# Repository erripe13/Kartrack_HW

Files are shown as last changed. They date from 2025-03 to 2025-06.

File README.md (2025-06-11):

# Kartrak – Hardware

> **Dépôts associés** :  
> - [Kartrack_SW](https://github.com/erripe13/Kartrack_SW) – Code embarqué STM32 (FreeRTOS, GPS, LoRa, SD...)  
> - [Kartrack_HW](https://github.com/erripe13/Kartrack_HW) – **Ce dépôt** – Schéma et PCB du système  
> - [Kartrack_APP](https://github.com/erripe13/Kartrack_APP) – Application d’analyse et visualisation des données

## Présentation du projet Kartrak

Kartrak est un système embarqué de chronométrage et de télémétrie pour karting, conçu pour être fixé sur le volant. Il enregistre en temps réel les données de course (position GPS, accélérations, orientation) et les transmet en LoRa à l'appli desktop et les enregistre sur carte microSD. L’objectif est de proposer un outil complet pour les pilotes amateurs ou en compétition : analyse post-course, visualisation en temps réel par l'équipe, appel aux stands, comparaisons de trajectoires.

---

Le projet est basé sur la plateforme **STM32F746G-DISCO**, exploitant son STM32 puissant et ses périphériques avancés (écran TFT, SDMMC, i2c, SPI, UART) pour accélérer le développement hardware, éliminant l'étape d'implémentation écran/uC.

Ce dépôt contient les fichiers **KiCad** du schéma électronique et du circuit imprimé (PCB) conçu pour le système embarqué Kartrack. Il s’agit d’une carte d’interface et d’alimentation destinée à supporter la carte **STM32F746G-DISCO** tout en intégrant les composants spécifiques au projet.

Le système est alimenté à partir de **deux batteries 18650** montées en **parallèle**. Un **convertisseur boost (step-up)** élève la tension à 5 V pour alimenter la carte STM32F7 Discovery via ses broches VIN (arduino) et GND. Ces 5V sont réutilisés et abaissés à 3.3V avec un LDO. Un autre LDO permet la recharge des batteries.

Le PCB a été conçu dans une logique de prototypage rapide :
- **Réduction du temps de conception** en réutilisant une carte STM32 existante (la DISCO) plutôt qu’un microcontrôleur nu.
- Embarque les modules suivants :
  - LoRa : RA-01 (SPI). Le Lora nous permet de couvrir un grand espace de communication (Piste de Karting) sans passer par le réseau GSM et a aussi l'a avantage d'une faible consommation électrique.
  - GPS : Quectel L76 (UART). Le grand avantage de ce GPS est sa fréquence élevée d'acquisition, ici 5Hz. La norme des GPS est de 1Hz, mais pour un kart à 60km/h sur une piste de 1000m la norme n'est pas suffisante.
  - IMU : ICM-42605 (I²C). L'accéléromètre et le gyroscope nous permettent d'ajouter une donnée en plus à notre pilote. Ici le gyro est réglé sur la mesure la plus rapide, et l'accélaration la plus élevée (16G). En cas d'accident par exemple cette donnée peut être des plus intéressantes.  
     
---

## À venir

- Intégration directe d’un STM32 nu sur une version 1 de ce projet, considérant celle-ci comme une bêta ou un POC.
- Création d'un boîtier en conséquence plus fin et plus petit, potentiellement étanche.
- Amélioration de la partie RF pour une meilleure fiabilité du GPS et une plus grande portée du LoRa.

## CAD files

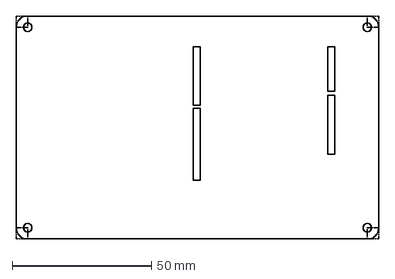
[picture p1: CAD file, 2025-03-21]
Mechanical/main_board_outline_and_arduino.dxf
130.0 x 80.0 mm

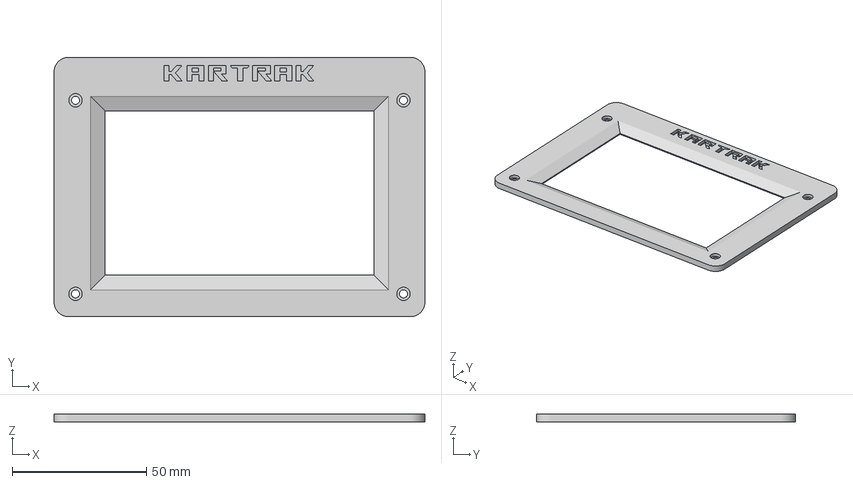
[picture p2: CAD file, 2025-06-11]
Mechanical/TOP_KARTRAK.3mf
138.0 x 96.5 x 3.00 mm

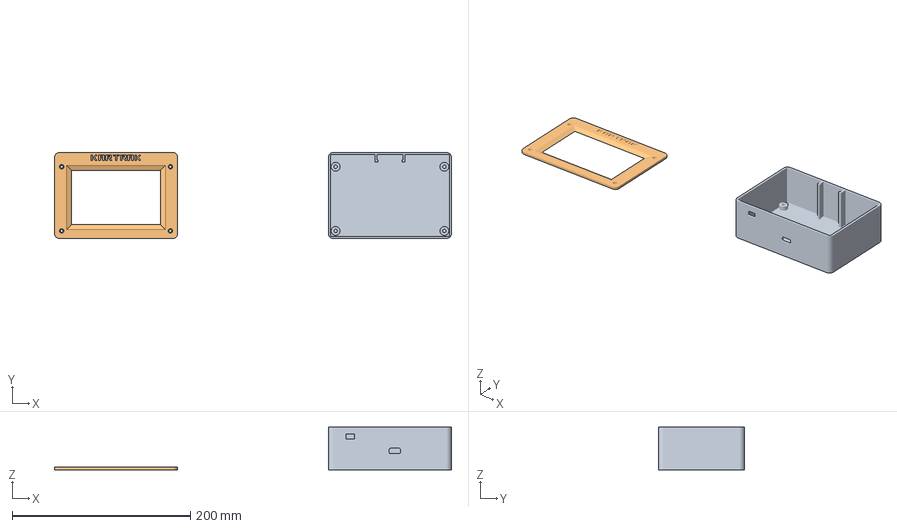
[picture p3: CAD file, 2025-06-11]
Mechanical/BOTTOM_KARTRAK.3mf
445.2 x 96.5 x 48.1 mm
BOTTOM_KARTRAK
TOP_KARTRAK

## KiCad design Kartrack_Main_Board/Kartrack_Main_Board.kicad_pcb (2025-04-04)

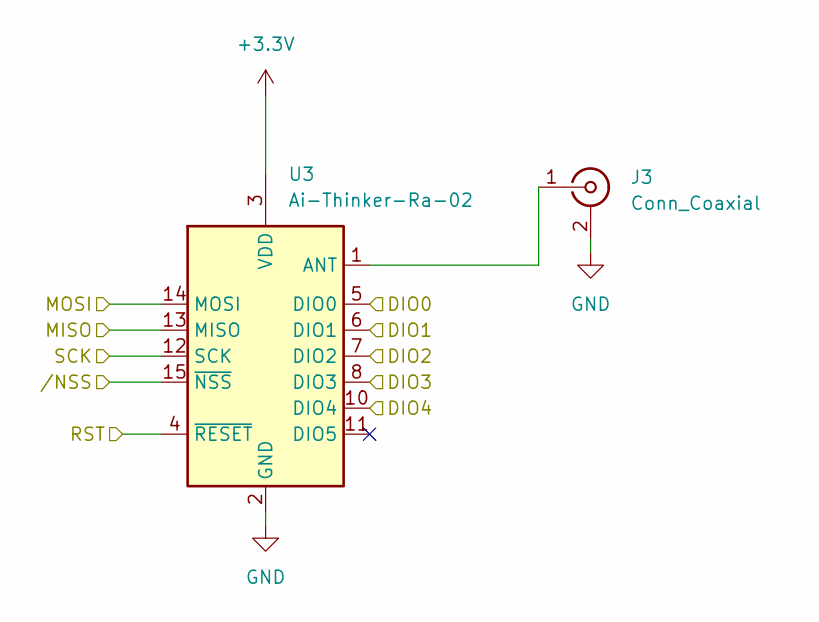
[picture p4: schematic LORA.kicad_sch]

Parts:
J3: Conn_Coaxial; U.FL_Molex_MCRF_73412-0110_Vertical
U3: Ai-Thinker-Ra-02; Ai-Thinker-Ra-01-LoRa

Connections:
+3.3V: U3.3 (VDD); also elsewhere on the board
/CONN/PA8: U3.8 (DIO3); also elsewhere on the board
/CONN/PA15: U3.7 (DIO2); also elsewhere on the board
/CONN/PB4: U3.10 (DIO4); also elsewhere on the board
/CONN/PB14_SPI2_MISO: U3.13 (MISO); also elsewhere on the board
/CONN/PB15_SPI2_MOSI: U3.14 (MOSI); also elsewhere on the board
/CONN/PF8_LORA_RST: U3.4 (~RESET); also elsewhere on the board
/CONN/PI1_SPI2_SCK: U3.12 (SCK); also elsewhere on the board
/CONN/PI2: U3.6 (DIO1); also elsewhere on the board
/CONN/PI3: U3.5 (DIO0); also elsewhere on the board
/CONN/PIO_SPI2_NSS: U3.15 (~NSS); also elsewhere on the board
GND: J3.2 (Ext), U3.2 (GND), U3.9 (GND), U3.16 (GND); also elsewhere on the board
unnamed: J3.1 (In), U3.1 (ANT)

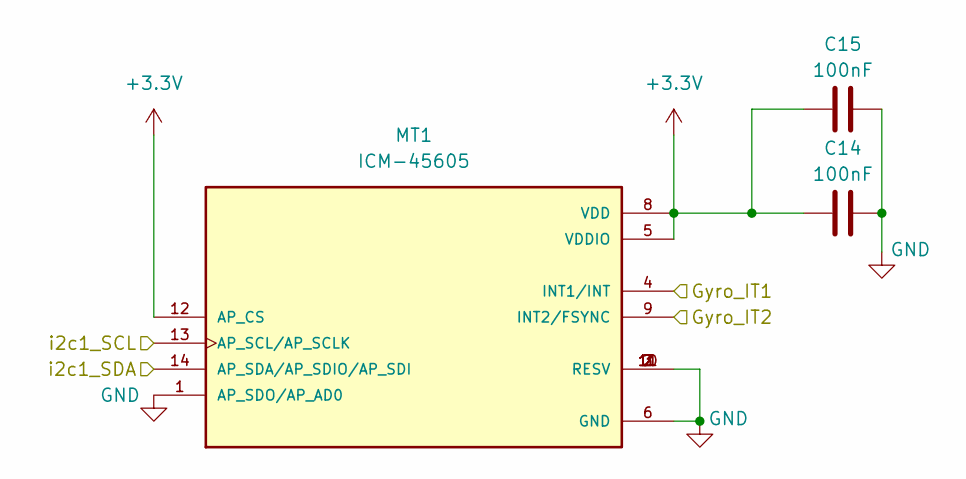
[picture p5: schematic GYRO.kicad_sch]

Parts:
C14, C15: 100nF; C_0402_1005Metric
MT1: ICM-45605; IC_ICM-45605; PARTREV 1.7

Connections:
+3.3V: C14.1, C15.1, MT1.5 (VDDIO), MT1.8 (VDD), MT1.12 (AP_CS); also elsewhere on the board
/CONN/PB8_SCL: MT1.13 (AP_SCL/AP_SCLK); also elsewhere on the board
/CONN/PB9_SDA: MT1.14 (AP_SDA/AP_SDIO/AP_SDI); also elsewhere on the board
/CONN/PF6: MT1.9 (INT2/FSYNC); also elsewhere on the board
/CONN/PG7: MT1.4 (INT1/INT); also elsewhere on the board
GND: C14.2, C15.2, MT1.1 (AP_SDO/AP_AD0), MT1.2 (RESV), MT1.3 (RESV), MT1.6 (GND), MT1.7 (RESV), MT1.10 (RESV), MT1.11 (RESV); also elsewhere on the board

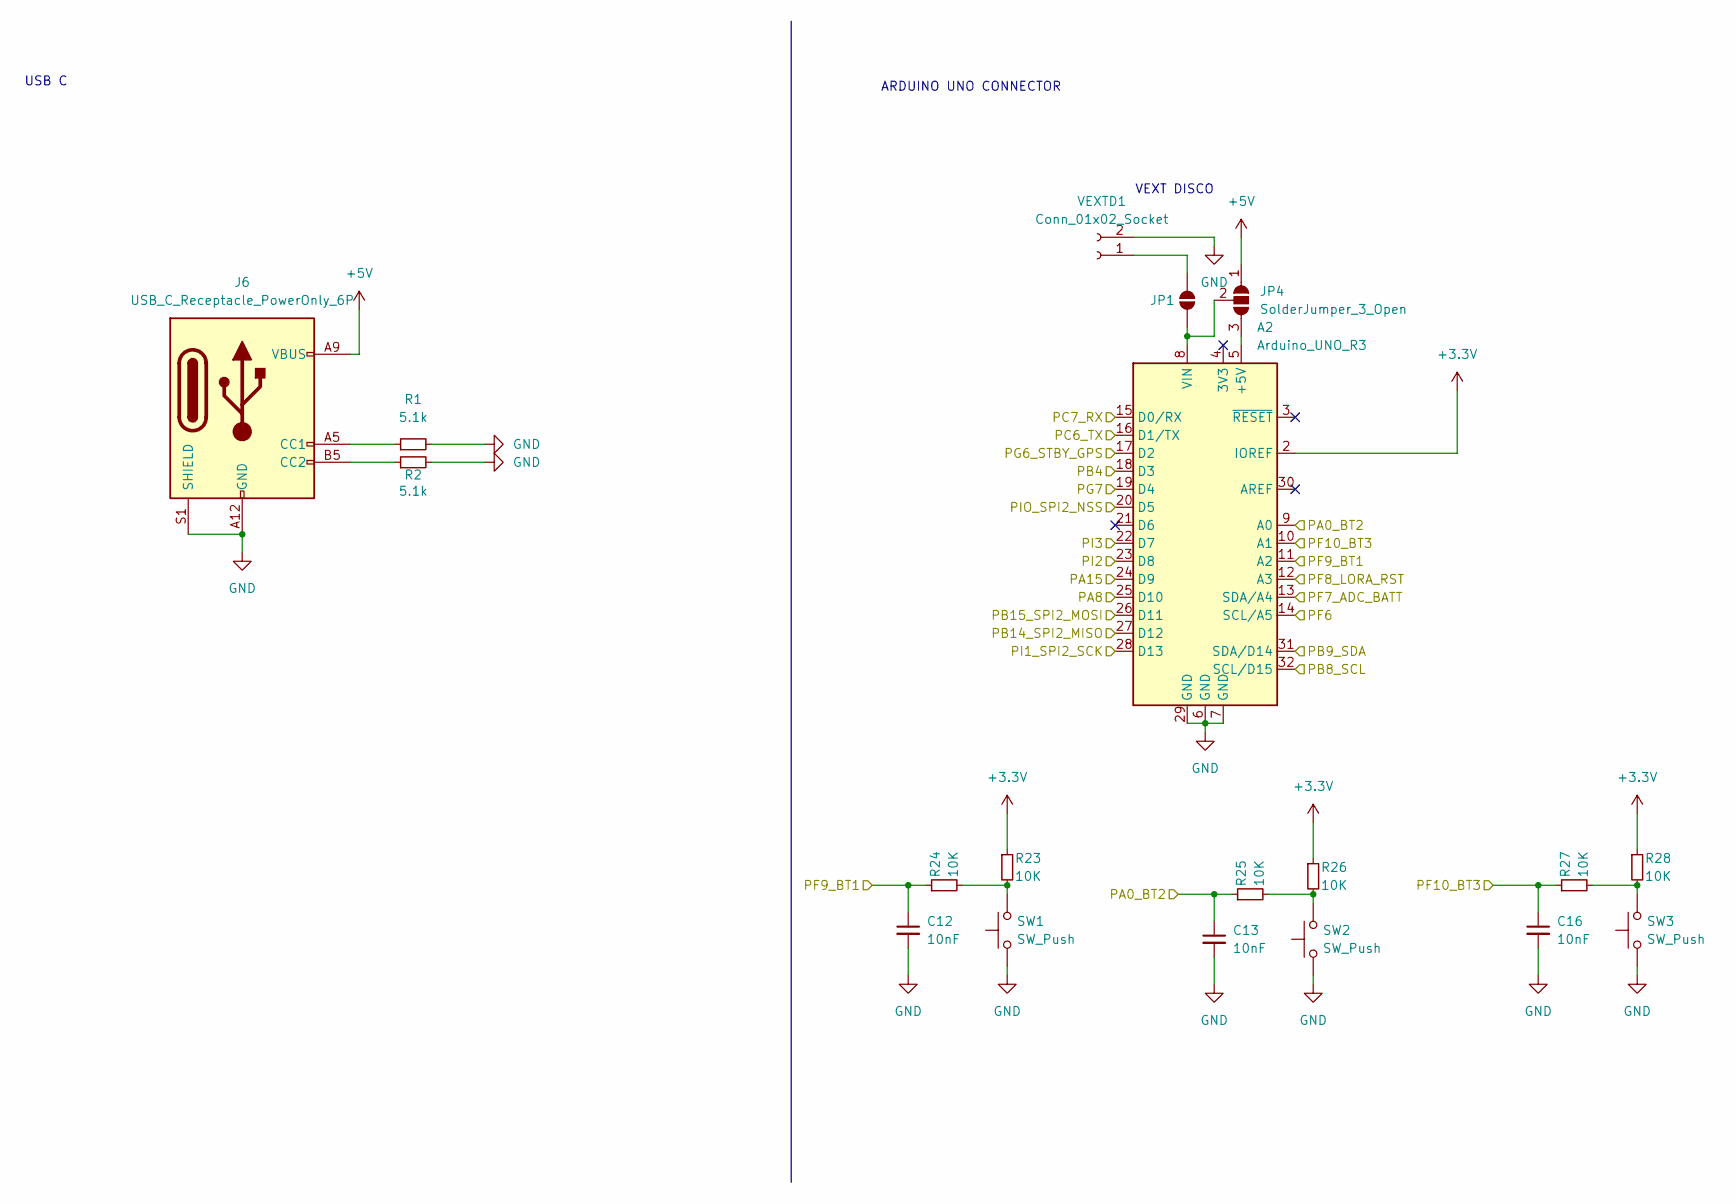
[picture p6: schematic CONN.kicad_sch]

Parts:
A2: Arduino_UNO_R3
C12, C13, C16: 10nF; C_0603_1608Metric
J6: USB_C_Receptacle_PowerOnly_6P; USB_C_Receptacle_GCT_USB4125-xx-x_6P_TopMnt_Horizontal
JP1: SolderJumper_2_Open; SolderJumper-2_P1.3mm_Open_RoundedPad1.0x1.5mm
JP4: SolderJumper_3_Open; SolderJumper-3_P2.0mm_Open_TrianglePad1.0x1.5mm_NumberLabels
R1, R2: 5.1k; R_0603_1608Metric
R23, R24, R25, R26, R27, R28: 10K; R_0603_1608Metric
SW1, SW2, SW3: SW_Push; JST_PH_S2B-PH-K_1x02_P2.00mm_Horizontal
VEXTD1: Conn_01x02_Socket; PhoenixContact_MC_1,5_2-G-3.81_1x02_P3.81mm_Horizontal

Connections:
+3.3V: A2.2 (IOREF), R23.1, R26.1, R28.1; also elsewhere on the board
+5V: J6.A9 (VBUS), J6.B9 (VBUS), JP4.1 (A); also elsewhere on the board
/ALIM/ADC_VBATT: A2.13 (SDA/A4); also elsewhere on the board
/CONN/PA0_BT2: A2.9 (A0), C13.1, R25.1
/CONN/PA8: A2.25 (D10); also elsewhere on the board
/CONN/PA15: A2.24 (D9); also elsewhere on the board
/CONN/PB4: A2.18 (D3); also elsewhere on the board
/CONN/PB8_SCL: A2.32 (SCL/D15); also elsewhere on the board
/CONN/PB9_SDA: A2.31 (SDA/D14); also elsewhere on the board
/CONN/PB14_SPI2_MISO: A2.27 (D12); also elsewhere on the board
/CONN/PB15_SPI2_MOSI: A2.26 (D11); also elsewhere on the board
/CONN/PC6_TX: A2.16 (D1/TX); also elsewhere on the board
/CONN/PC7_RX: A2.15 (D0/RX); also elsewhere on the board
/CONN/PF6: A2.14 (SCL/A5); also elsewhere on the board
/CONN/PF8_LORA_RST: A2.12 (A3); also elsewhere on the board
/CONN/PF9_BT1: A2.11 (A2), C12.1, R24.1
/CONN/PF10_BT3: A2.10 (A1), C16.1, R27.1
/CONN/PG6_STBY_GPS: A2.17 (D2); also elsewhere on the board
/CONN/PG7: A2.19 (D4); also elsewhere on the board
/CONN/PI1_SPI2_SCK: A2.28 (D13); also elsewhere on the board
/CONN/PI2: A2.23 (D8); also elsewhere on the board
/CONN/PI3: A2.22 (D7); also elsewhere on the board
/CONN/PIO_SPI2_NSS: A2.20 (D5); also elsewhere on the board
GND: A2.6 (GND), A2.7 (GND), A2.29 (GND), C12.2, C13.2, C16.2, J6.A12 (GND), J6.B12 (GND), J6.S1 (SHIELD), R1.2, R2.2, SW1.1, SW2.1, SW3.1, VEXTD1.2; also elsewhere on the board
unnamed: A2.5 (+5V), JP4.3 (B)
unnamed: A2.8 (VIN), JP1.1 (A), JP4.2 (C)
unnamed: J6.A5 (CC1), R1.1
unnamed: J6.B5 (CC2), R2.1
unnamed: JP1.2 (B), VEXTD1.1
unnamed: R23.2, R24.2, SW1.2
unnamed: R25.2, R26.2, SW2.2
unnamed: R27.2, R28.2, SW3.2

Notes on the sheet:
USB C
ARDUINO UNO CONNECTOR
VEXT DISCO

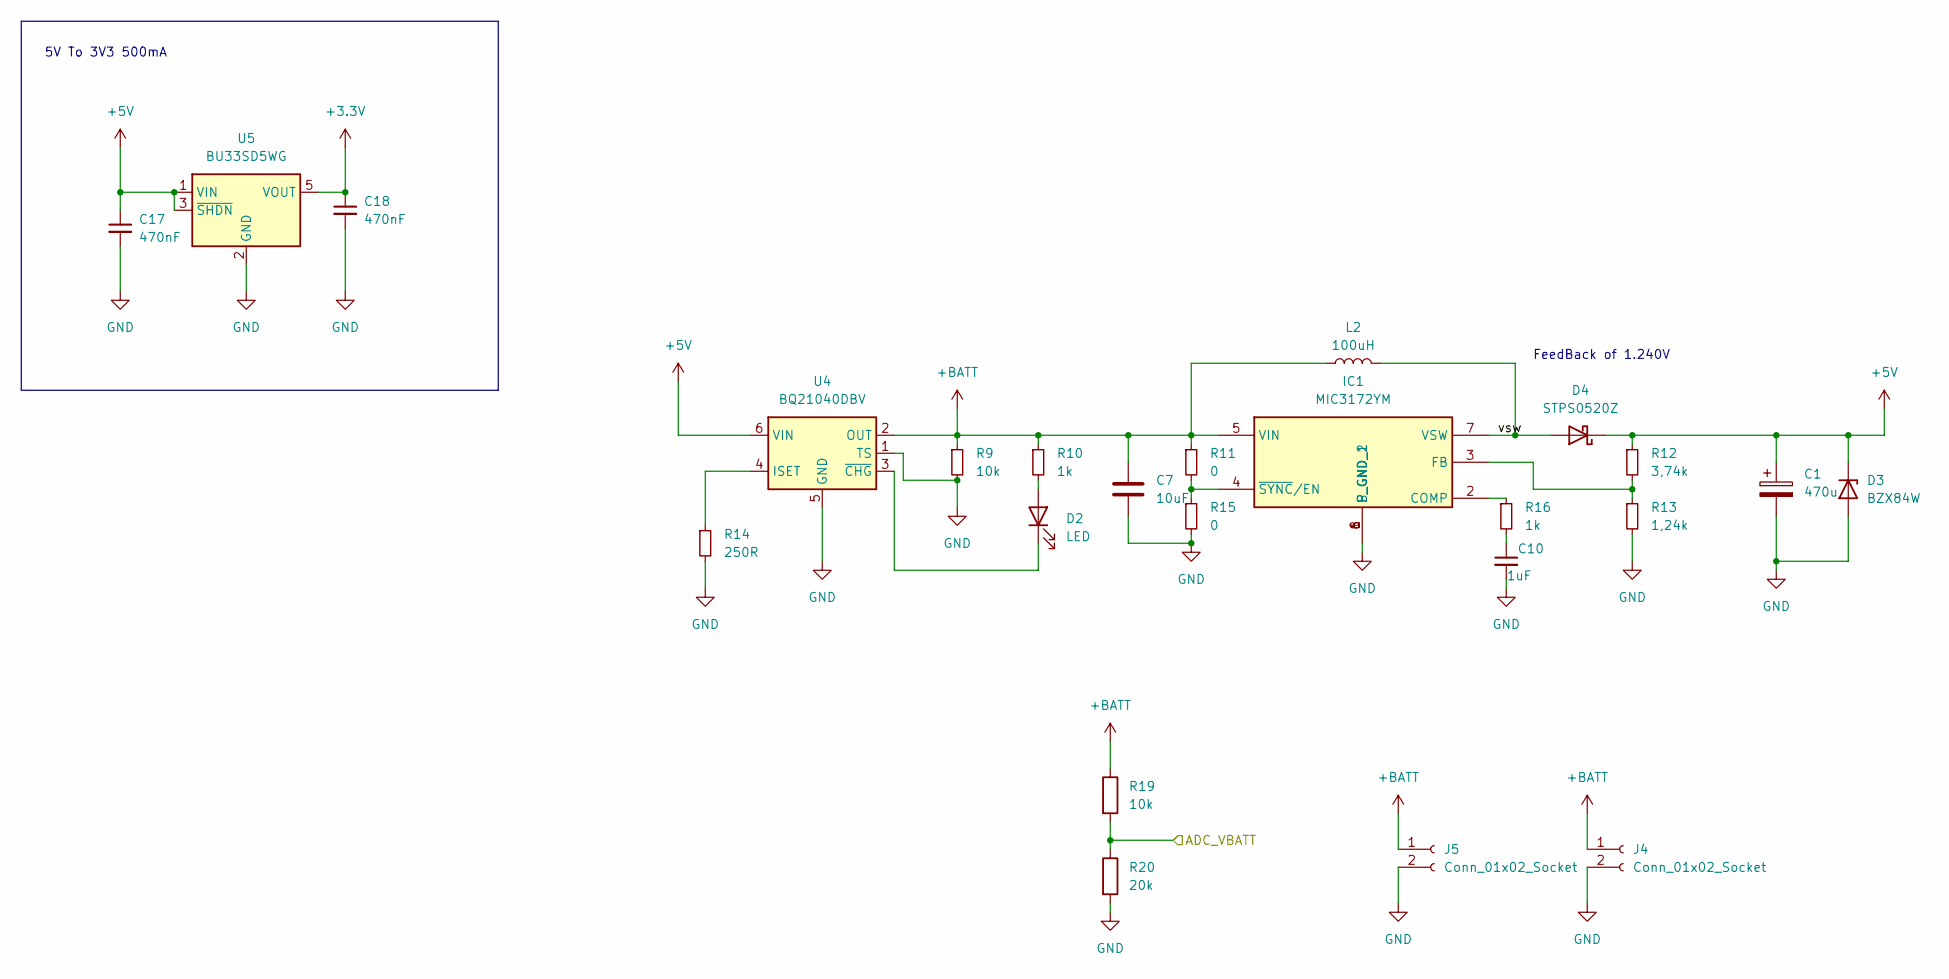
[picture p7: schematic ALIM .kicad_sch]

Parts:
C1: 470u; CP_Elec_8x10
C7: 10uF; C_0603_1608Metric
C10: 1uF; C_0603_1608Metric
C17, C18: 470nF; C_0603_1608Metric
D2: LED; LED_0603_1608Metric
D3: BZX84W; SOT-23
D4: STPS0520Z; D_SOD-123
IC1: MIC3172YM; SOIC127P599X173-8N; MPN MIC3172YM; Mouser Part Number 998-MIC3172YM
J4, J5: Conn_01x02_Socket; BatteryHolder_MPD_BH-18650-PC2
L2: 100uH; L_12x12mm_H8mm
R9, R19: 10k; R_0603_1608Metric
R10, R16: 1k; R_0603_1608Metric
R11, R15: 0; R_0603_1608Metric
R12: 3,74k; R_0603_1608Metric; MPN CRCW06033K74DHEAP
R13: 1,24k; R_0603_1608Metric; MPN CRCW06031K24FKEAHP
R14: 250R; R_0603_1608Metric
R20: 20k; R_0603_1608Metric
U4: BQ21040DBV; SOT-23-6; MPN BQ21040DBVR
U5: BU33SD5WG; SOT-23-5; MPN BU33SD5WG-TR

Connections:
+3.3V: C18.1, U5.5 (VOUT); also elsewhere on the board
+5V: C1.1, C17.1, D3.3 (K), D4.1 (K), R12.1, U4.6 (VIN), U5.1 (VIN), U5.3 (~SHDN); also elsewhere on the board
+BATT: C7.1, IC1.5 (VIN), J4.1, J5.1, L2.1, R9.1, R10.1, R11.1, R19.1, U4.2 (OUT)
/ALIM/ADC_VBATT: R19.2, R20.1; also elsewhere on the board
/ALIM/vsw: D4.2 (A), IC1.7 (VSW), L2.2
GND: C1.2, C7.2, C10.2, C17.2, C18.2, D3.1 (A), IC1.1 (S_GND), IC1.6 (P_GND_2), IC1.8 (P_GND_1), J4.2, J5.2, R9.2, R13.2, R14.2, R15.2, R20.2, U4.1 (TS), U4.5 (GND), U5.2 (GND); also elsewhere on the board
unnamed: C10.1, R16.2
unnamed: D2.2 (A), R10.2
unnamed: D2.1 (K), U4.3 (~CHG)
unnamed: IC1.2 (COMP), R16.1
unnamed: IC1.3 (FB), R12.2, R13.1
unnamed: IC1.4 (~SYNC/EN), R11.2, R15.1
unnamed: R14.1, U4.4 (ISET)

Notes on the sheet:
5V To 3V3 500mA
FeedBack of 1.240V

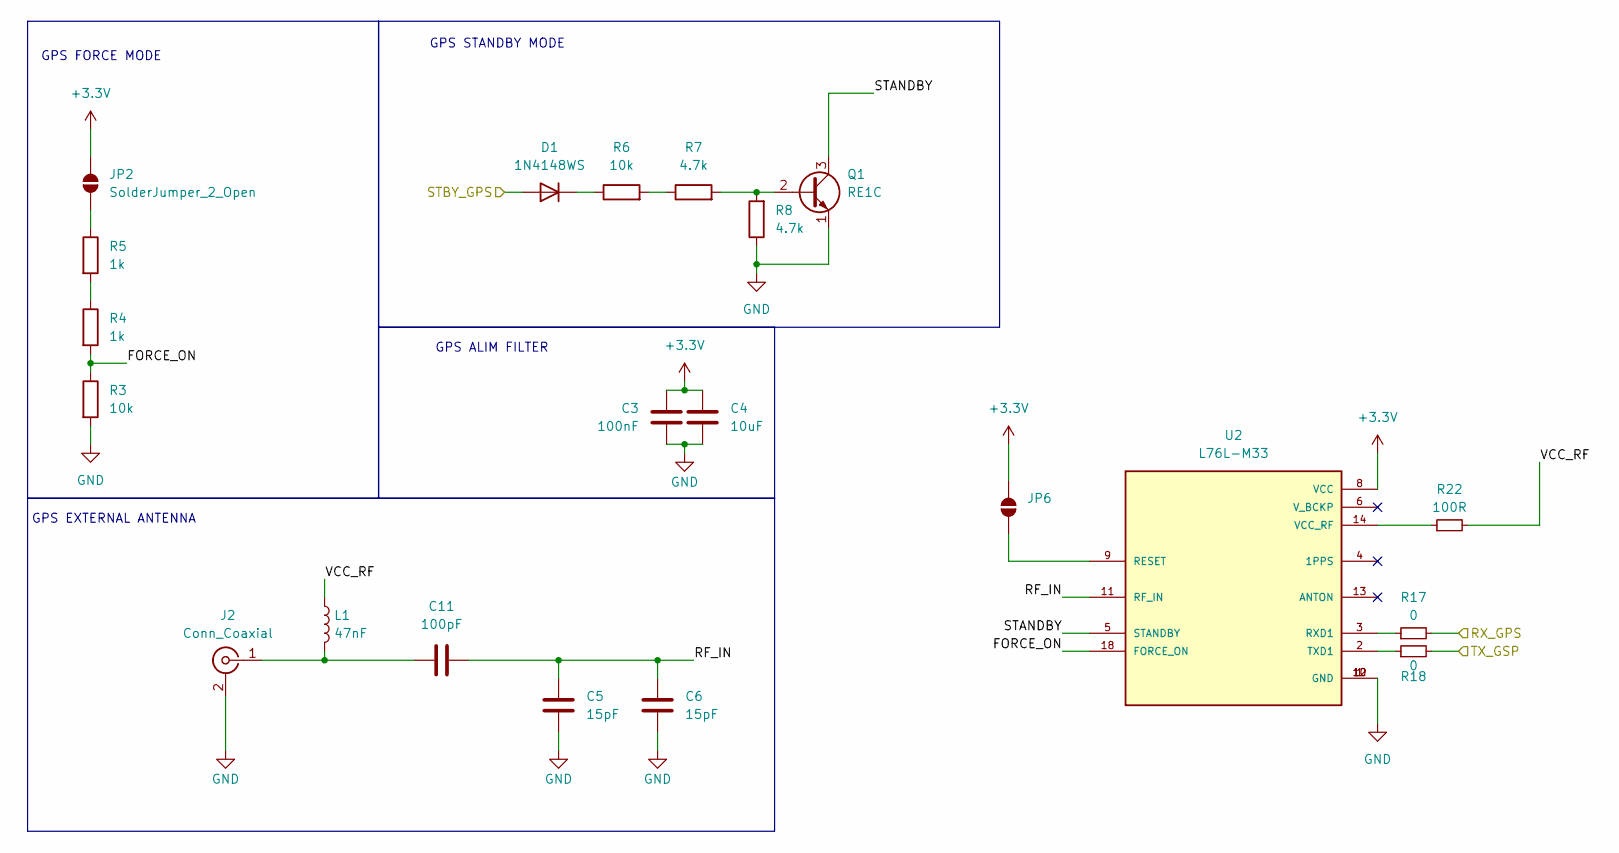
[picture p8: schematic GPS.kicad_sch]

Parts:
C3: 100nF; C_0603_1608Metric
C4: 10uF; C_0603_1608Metric
C5, C6: 15pF; C_0603_1608Metric
C11: 100pF; C_0603_1608Metric
D1: 1N4148WS; D_SOD-323
J2: Conn_Coaxial; U.FL_Molex_MCRF_73412-0110_Vertical
JP2, JP6: SolderJumper_2_Open; SolderJumper-2_P1.3mm_Open_RoundedPad1.0x1.5mm
L1: 47nF; L_0603_1608Metric
Q1: RE1C; SOT-416
R3, R6: 10k; R_0603_1608Metric
R4, R5: 1k; R_0603_1608Metric
R7, R8: 4.7k; R_0603_1608Metric
R17, R18: 0; R_0603_1608Metric
R22: 100R; R_0603_1608Metric
U2: L76L-M33; XCVR_L76L-M33; DigiKey_Part_Number 2958-L76L-M33TR-ND

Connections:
+3.3V: C3.1, C4.1, JP2.2 (B), JP6.2 (B), U2.8 (VCC); also elsewhere on the board
/CONN/PC6_TX: R17.2; also elsewhere on the board
/CONN/PC7_RX: R18.2; also elsewhere on the board
/CONN/PG6_STBY_GPS: D1.2 (A); also elsewhere on the board
/GPS/FORCE_ON: R3.1, R4.2, U2.18 (FORCE_ON)
/GPS/RF_IN: C5.1, C6.1, C11.2, U2.11 (RF_IN)
/GPS/STANDBY: Q1.3 (C), U2.5 (STANDBY)
/GPS/VCC_RF: L1.1, R22.2
GND: C3.2, C4.2, C5.2, C6.2, J2.2 (Ext), Q1.1 (E), R3.2, R8.1, U2.1 (GND), U2.10 (GND), U2.12 (GND); also elsewhere on the board
unnamed: D1.1 (K), R6.1
unnamed: C11.1, J2.1 (In), L1.2
unnamed: JP2.1 (A), R5.1
unnamed: JP6.1 (A), U2.9 (RESET)
unnamed: Q1.2 (B), R7.2, R8.2
unnamed: R4.1, R5.2
unnamed: R6.2, R7.1
unnamed: R17.1, U2.3 (RXD1)
unnamed: R18.1, U2.2 (TXD1)
unnamed: R22.1, U2.14 (VCC_RF)

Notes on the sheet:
GPS EXTERNAL ANTENNA
GPS STANDBY MODE
GPS ALIM FILTER
GPS FORCE MODE

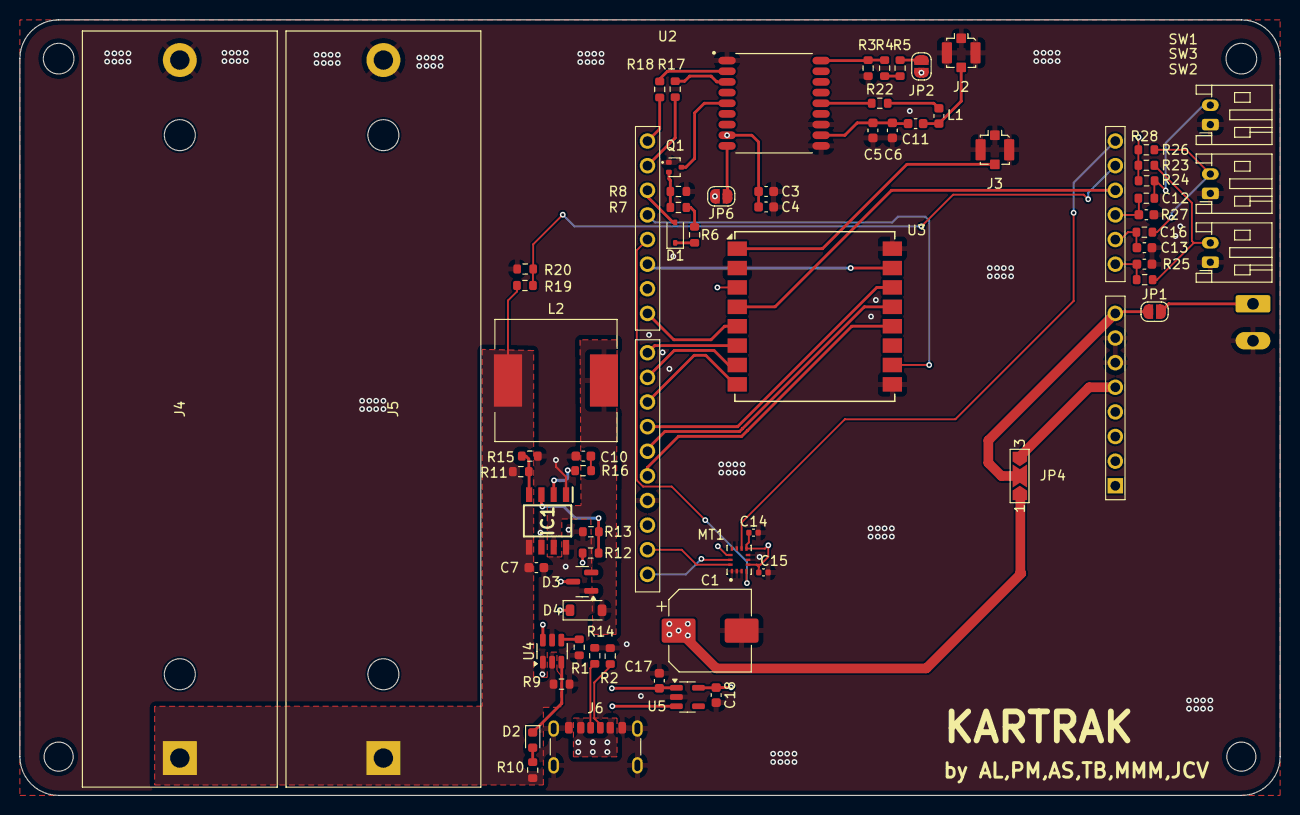
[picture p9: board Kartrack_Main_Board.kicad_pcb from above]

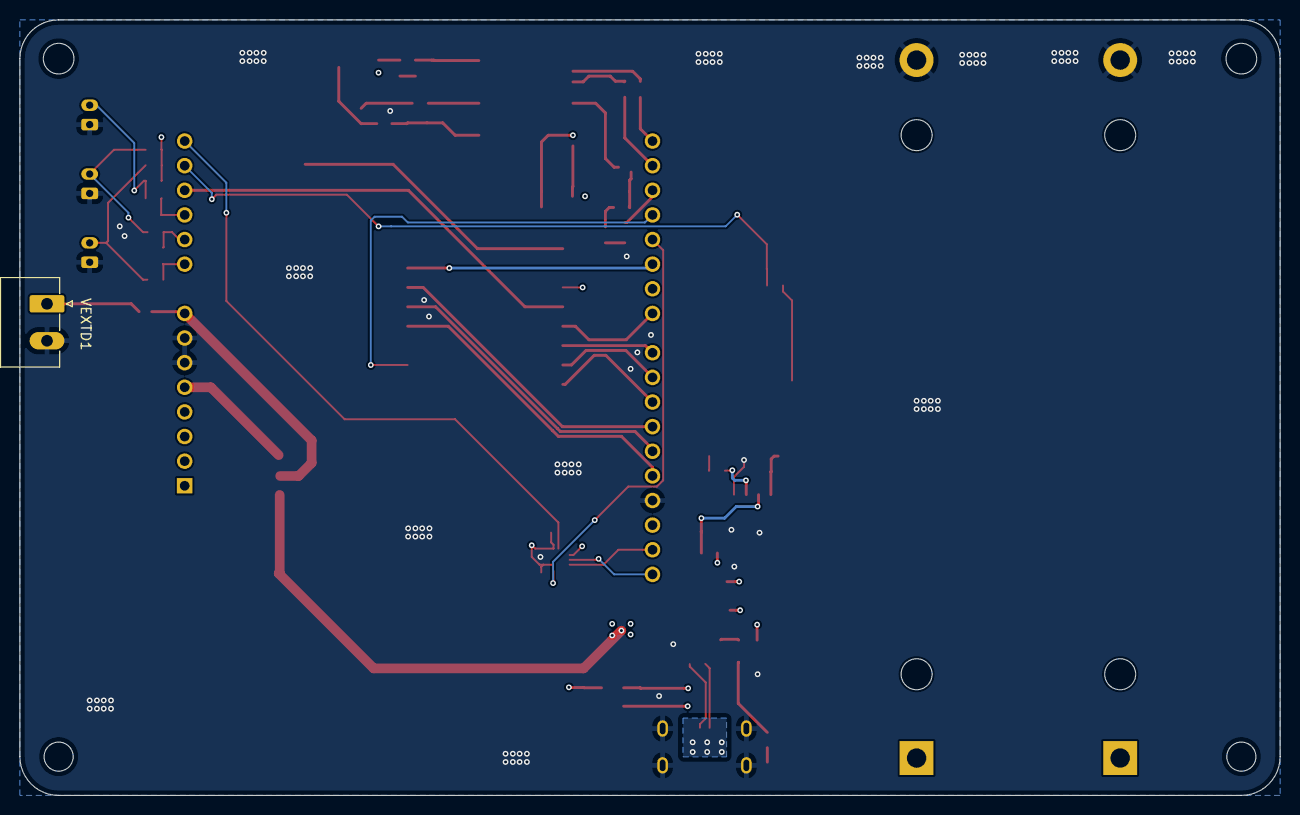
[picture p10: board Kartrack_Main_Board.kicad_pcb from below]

Board: 4 copper layers, 130.0 x 80.0 mm, 69 parts (2 on the bottom side), 56 nets.

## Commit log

2025-03-14 Project Creation
    [Kartrack_Main_Board.kicad_pcb, Kartrack_Main_Board.kicad_sch]
2025-03-14 arduino footprint
2025-03-14 arduino layout
    [Kartrack_Main_Board.kicad_pcb, Kartrack_Main_Board.kicad_sch]
2025-03-21 schematic GPS
    [ALIM .kicad_sch, CONN.kicad_sch, GPS.kicad_sch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]
2025-03-21 added power IC datasheet
2025-03-21 FIn de séance
    [Kartrack_Main_Board.kicad_pcb, Kartrack_Main_Board.kicad_sch]
2025-03-26 buck schematic
    [ALIM .kicad_sch]
2025-03-27 buck verif
    [ALIM .kicad_sch]
2025-03-28 BLOC schematic
    [CONN.kicad_sch, GPS.kicad_sch, Kartrack_Main_Board.kicad_sch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]
2025-03-28 ajouts des boutons
    [CONN.kicad_sch]
2025-03-28 added connectors for pulldown pushbuttons
    [CONN.kicad_sch, GYRO.kicad_sch]
2025-03-28 add filtering button
    [ALIM .kicad_sch, CONN.kicad_sch]
2025-03-28 SCHEMATIC FINISHED
    [ALIM .kicad_sch, CONN.kicad_sch, GPS.kicad_sch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]
2025-03-28 PCB early
    [ALIM .kicad_sch, CONN.kicad_sch, GPS.kicad_sch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]
2025-03-28 update Alim
    [ALIM .kicad_sch]
2025-03-29 Routing alim
    [ALIM .kicad_sch, Kartrack_Main_Board.kicad_pcb]
2025-04-03 PCB V1
    [CONN.kicad_sch, Kartrack_Main_Board.kicad_pcb]
2025-04-03 add adc batt
    [ALIM .kicad_sch, CONN.kicad_sch, Kartrack_Main_Board.kicad_pcb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]
2025-04-03 meca update
    [Kartrack_Main_Board.kicad_pcb]
2025-04-04 pcb via in pad remove
    [Kartrack_Main_Board.kicad_pcb]
2025-04-04 kartrack logo
    [Kartrack_Main_Board.kicad_pcb]
2025-04-04 Alim jumper
    [CONN.kicad_sch]
2025-04-04 production files
    [Kartrack_Main_Board.kicad_pcb]
2025-06-11 mechanical update & datasheet
    [BOTTOM_KARTRAK.3mf, TOP_KARTRAK.3mf]
